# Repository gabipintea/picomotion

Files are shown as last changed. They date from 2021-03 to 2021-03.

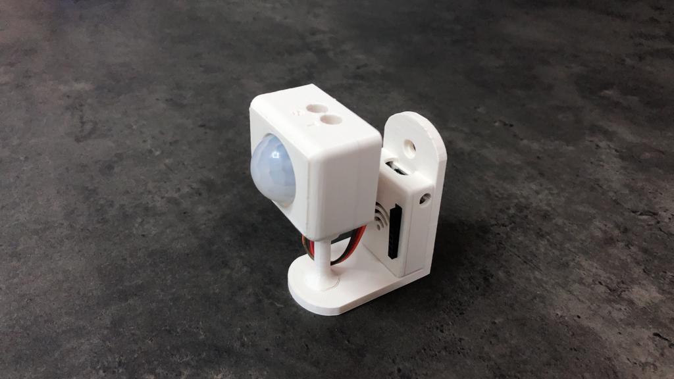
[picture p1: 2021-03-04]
pics/pic1.jpeg

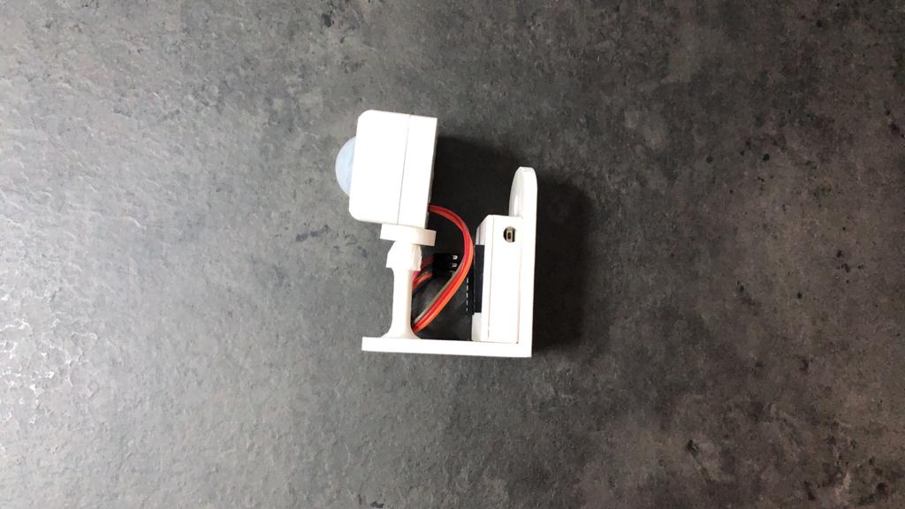
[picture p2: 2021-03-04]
pics/pic4.jpeg

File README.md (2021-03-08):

# PicoMotion - simple motion sensor for Home Assistant
PicoMotion is an open-source, simple, ready-to-mount, and ready-to-use motion sensor designed to be easily mounted on a wall, even upside down, to be easily adjusted for the use case and to flawlessly work within Home Assistant, by the means of ESPHome.

## Hardware
The hardware is comprised of:
- WeMos D1 Mini ESP8255 Development Board
- HC-SR501 PIR Sensor
- 3 Jumper wires + optional D1 mini headers
- 3D printed enclosure (STLs provided)
- 5V/1Amp DC Power supply
- micro-USB cable
- appropriate mounting screw

## Software
The firmware is written with ESPHome tool, flashed either via ESPHome-flasher, or from ESPHome Add-on within Home Assistant the first time. Afterward it can be OTA flashed. (both .yaml and compiled .bin provided)

## Open-source
As the sensor is made using open-source hardware and software, the whole kit is also open-source, so feel free to come up with feedback, use it, improve it and share it.

Thanks to Home Assistant and ESPHome! The core of the sensor is based on these two amazing pieces of software.

#### Adding to the below instructions, I highly recommend reading the Quick Start guide, provided in this repo.

## Instructions
1. After you got all the needed parts, you need to flash the firmware on the D1 mini.

Method 1: Download and use the .bin file in this repo, connect your D1 mini/ESP-based MCU to your PC using a micro-USB cable and flash the file on the board using ESPHome-flasher utility, for your OS. (https://github.com/esphome/esphome-flasher/releases)

Method 2: If you already have ESPHome Add-on installed, then create a new node, use and modify accordingly the .yaml file provided in this repo and flash your D1 mini directly from the system running ESPHome.

2. Disconnect power and connect the PIR Sensor to GND, 5V and Signal pin (default: D4 on D1 mini, for visual blue led feedback on motion detection).

3. Use the recommended 5V/1Amp DC power supply for powering the D1.

4. If you have added a new node in ESPHome Add-on and changed the WiFI SSID already, then your device should appear online after a few seconds and be recognized by auto-discovery feature of your Home Assistant.
If you did flashed the .bin file in this repo, then wait a few minutes, as the D1 will fail to connect to the SSID a few times and will eventually enable a hotspot AP, named Picomotion X (where X should be a unique number across your PicoMotion devices on the local network). Connect to the hotspot, dismiss the alerts of having "No Internet", navigate to http://192.168.4.1 using a browser, select your preffered WiFi network, type the password and hit "Save". The D1 will reboot and connect to your WiFi network.

5. After Home Assistant dicovery notfies you (if not, you can trigger that by manually restarting the Server), you can configure the new ESPHome node using the Integrations wizard and providing the api password, which is set in the .yaml file. You will get by default a motion class binary sensor, which gets triggered by warm bodies, like humans/animals. 
#### Note: If using the provided .bin file, the random api password for the provided sample is: HDLlLT2YEIci

6. Enjoy using the motion sensor in your light automations, presence detection ideas, alarm system or whatever. You can adjust the sensitivity and delay after trigger, using the two knobs, on top of the sensor.

## 3D enclosure instructions
1. Slice the STLs in your preffered slicer. The settings in CURA 4.8.0, for a Creality Ender-5, used for printing the sample in the pictures are:
- 0.2 layer height
- 20% infill
- 1.2 wall thickness
- 200C print temperature (differs for each material; for the sample Premium PLA/PHA was used)
- 40mm/s print speed
- Touching Buildplate support (for the sensor bottom especially)

2. Insert the D1 mini in the case, letting the headers facing upwards and use a small amount of superglue, to fix it on the back of the support.

3. Mount the support on the wall, using the appropiate screw for your material.

4. Push the PIR sensor in the case, connect 3 jumper wires to the pins on the back, assemble the back of the sensor.

5. Insert the printed tightening ring onto the shaft of the sensor, insert the sensor on the spherical mount, adjust it's position and secure it by pulling down the ring.

6. Connect the jumper wires to the D1 on the left-side header, from top to bottom (5V, GND, D4).

Credits:
- Home Assistant (https://www.home-assistant.io/)
- ESPHome (https://esphome.io/)
- Thingiverse (https://www.thingiverse.com/)
    
    especially:

        - BrainFever (https://www.thingiverse.com/brainfever/designs)
        
        - Electronlibre (https://www.thingiverse.com/electronlibre/designs)
        
        - Hills8 (https://www.thingiverse.com/hills8/designs)

## Picromatics

If you need something already made, the kit, the plug-n-play device, the 3D printed case or you just want to know more about me and my IoT company, write me an email or find me on LinkedIn/Facebook.

#### https://picromatics.com
#### contact@picromatics.com
#### gabriel.eugen.pintea@gmail.com

Turn your “dumb” home into a Smart Home! Picromatics develops professional IoT Solutions and offers Smart Integration Services for all your needs, being your beloved home or your business. 

IT & IoT Consulting services, Smart Home integration, custom hardware development, custom software development, product design, 3D printing and more...

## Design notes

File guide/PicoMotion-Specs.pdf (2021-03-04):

Datasheet and Specifications

- WeMos D1 Mini ESP8255 Development Board

Overview
This mini development board is based on the ESP-8266EX chip and is useful for applications that need wireless data transmission (2.4GHz). It is compatible with Arduino IDE and NodeMCU firmware. It features 11 digital input/output pins, all pins support interrupt/PWM/I2C/one-wire (except D0), and 1 analog input with 3.3V
maximum input. With this product, you can build innovative projects like you can control lights or appliances in the house.

Specifications
Chip: ESP-8266EX
Compatible with Arduino IDE Compatible NodeMCU firmware GPIO pins: 11
1 pin ADC (0 V to 3.3 V)
Max Input Voltage: 24 V
Operating Frequency: 80 / 160 MHz Flash Memory: 4MB
I2C interface
Size: 34.2 x 25.6 mm
- HC-SR501 PIR Sensor

Overview
The HC-SR501 sensor is based on pyroelectric infrared technology, it features high sensitivity, high reliability, and low-voltage operation. It is widely used in alarms and auto-sensing electrical equipment, especially in battery-operated products.

Specifications:
Operating Voltage Range: 5 V to 20 V
Power Consumption: 65 mA
TTL Output: 3.3 V, 0 V
Lock Time: 0.2 sec
Sensing Range: <120°, within 7 meters Temperature Range: -15° C to +70°
- 3D printed enclosure

The enclosure is made out of premium PLA/PHA material, non-toxic, with no odor. It is created using FDM 3D printing technology.
Note: Take note of the fact, that 3D printing can offer great quality, but as the printing technology is not yet flawless, there may be some minor artifacts, that does not affect the functionality of the case. (e.g. layer lines, plastic blobs, stringing lines, etc.)

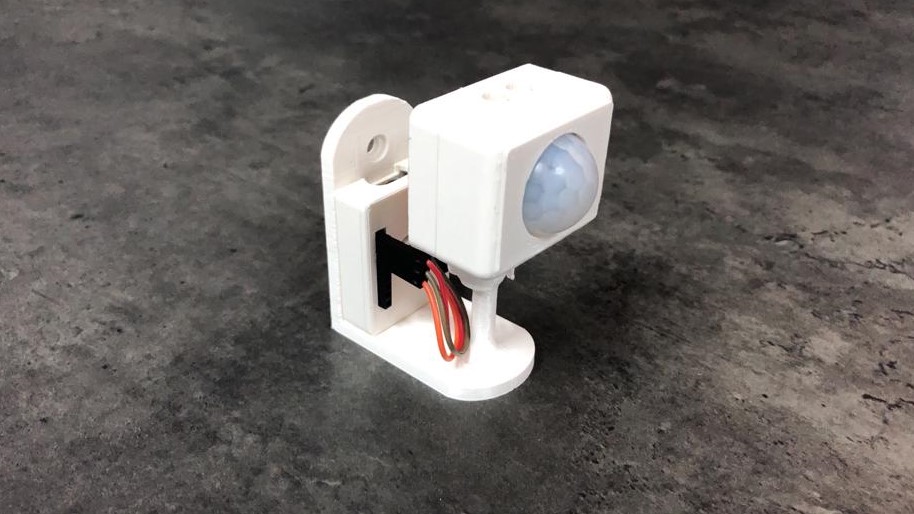
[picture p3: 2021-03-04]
pics/pic2.jpeg

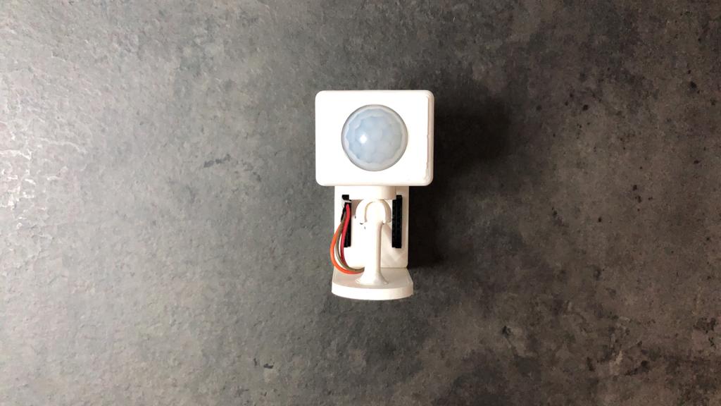
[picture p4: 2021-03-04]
pics/pic3.jpeg

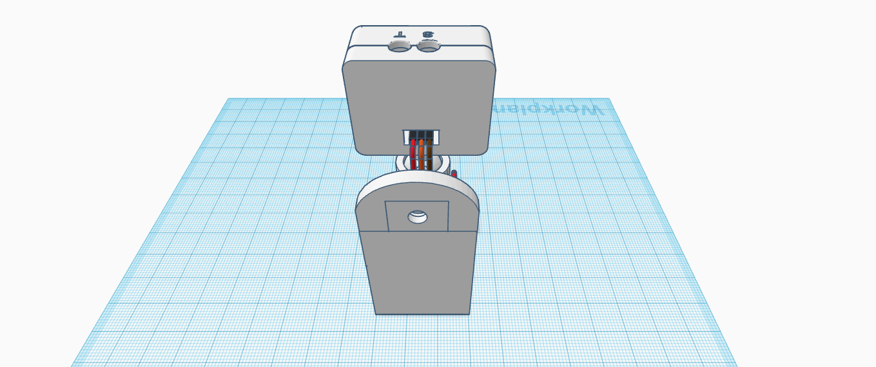
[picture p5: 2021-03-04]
3D/PicoMotion-2021-01 (3).png

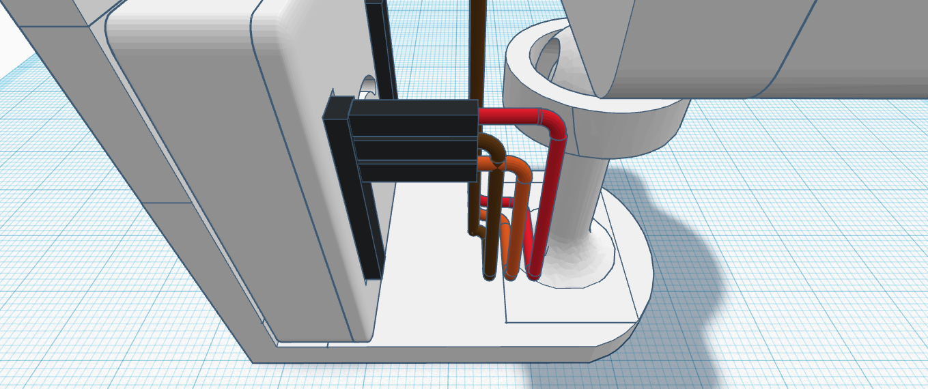
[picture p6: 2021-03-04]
3D/PicoMotion-2021-01 (4).png

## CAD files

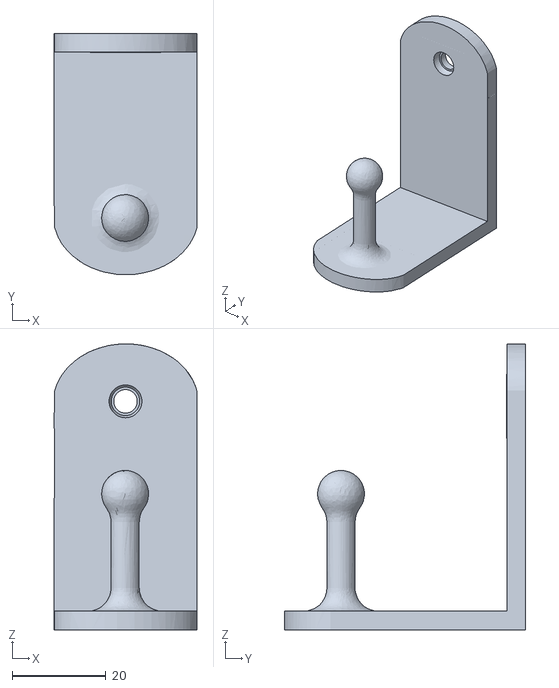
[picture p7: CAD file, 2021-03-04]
3D/stl/PicoMotion-2021-01-Wall_Support.stl
30.4 x 51.4 x 60.9

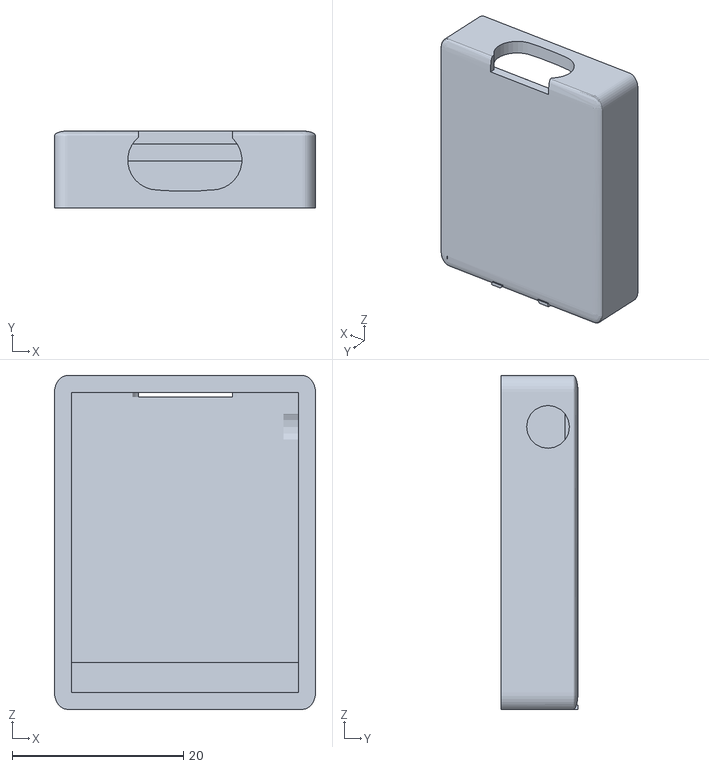
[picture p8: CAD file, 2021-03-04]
3D/stl/PicoMotion-2021-01-D1-Base.stl
30.5 x 9.00 x 39.0

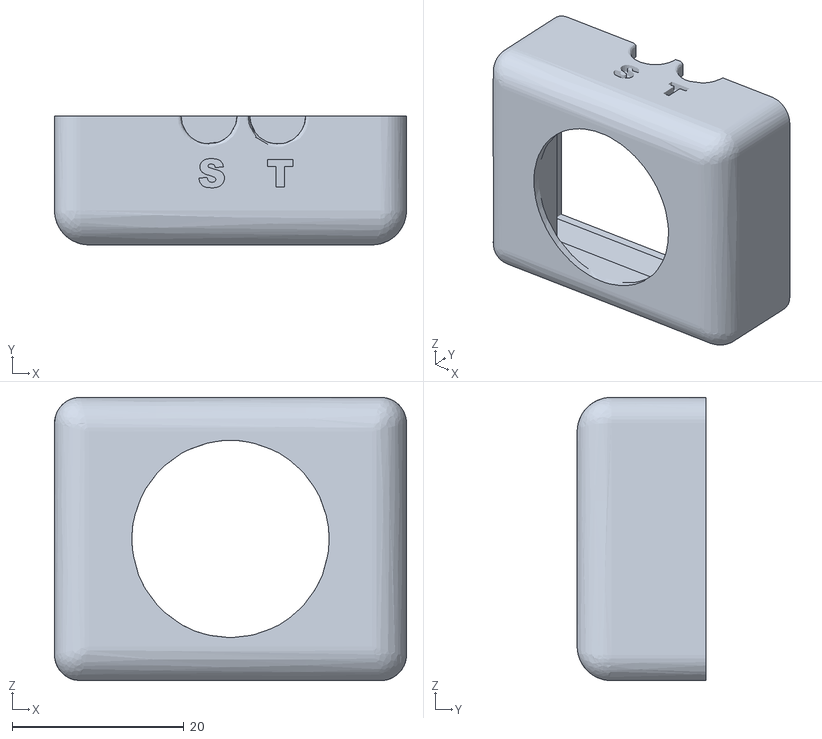
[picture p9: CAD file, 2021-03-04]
3D/stl/PicoMotion-2021-01-Sensor_Top.stl
41.0 x 15.0 x 33.0

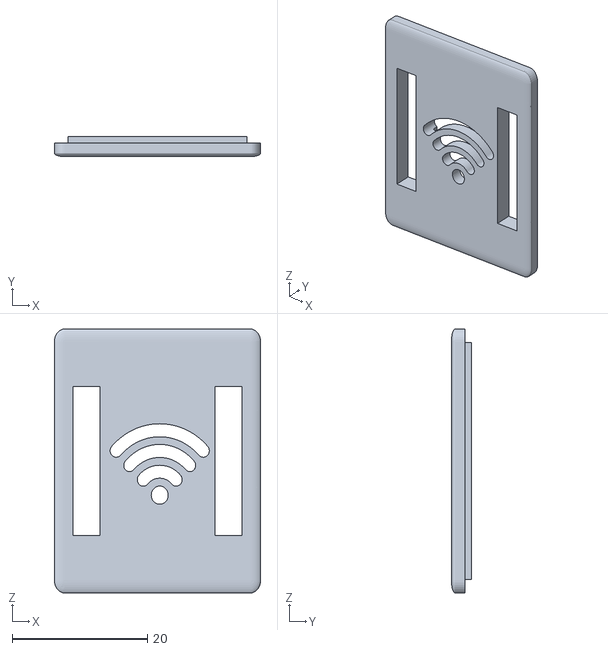
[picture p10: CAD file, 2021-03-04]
3D/stl/PicoMotion-2021-01-D1-Lid.stl
30.5 x 3.00 x 39.0

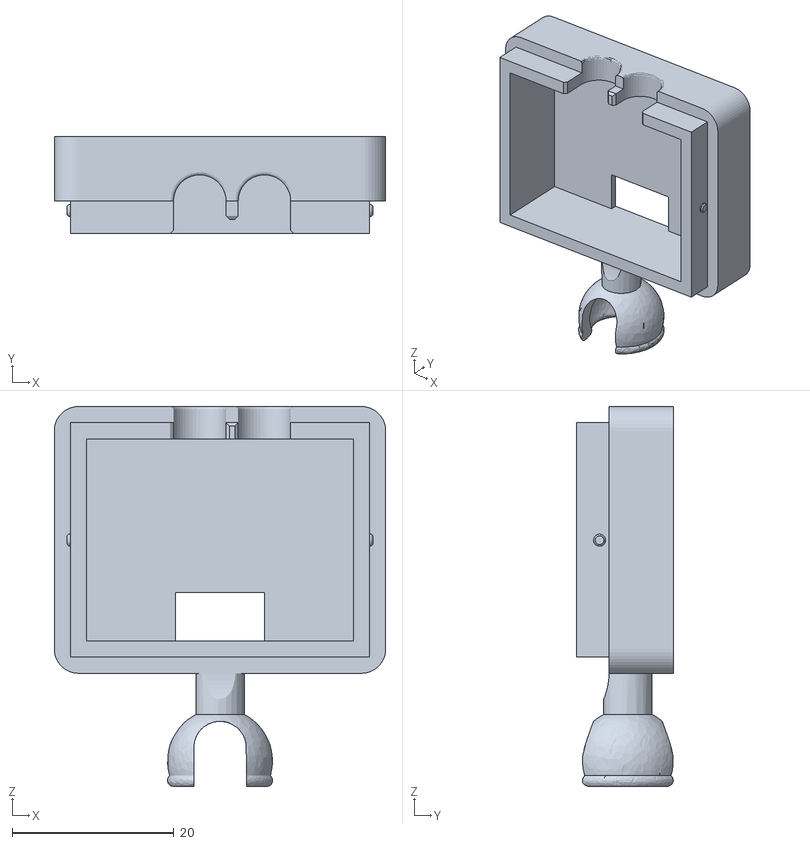
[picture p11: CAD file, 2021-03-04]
3D/stl/PicoMotion-2021-01-Sensor_Base.stl
41.0 x 12.0 x 47.0

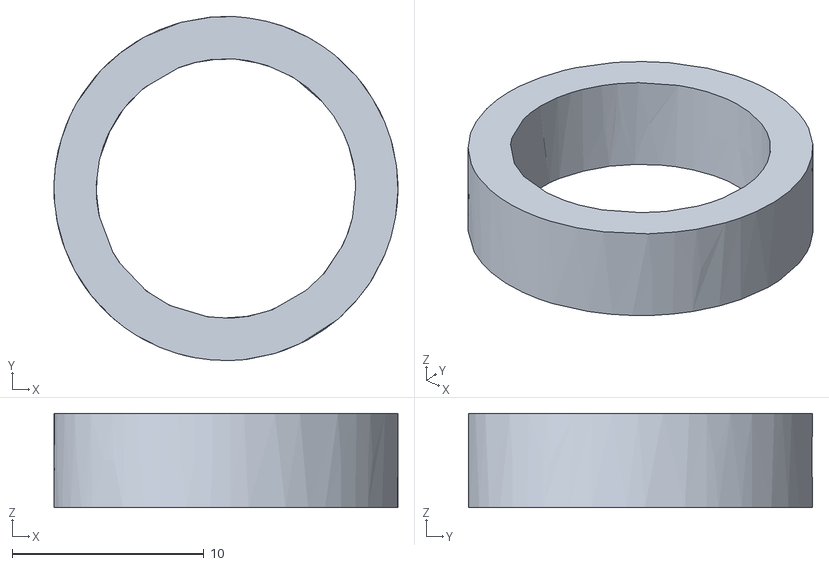
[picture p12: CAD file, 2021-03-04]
3D/stl/PicoMotion-2021-01-Ring.stl
18.0 x 18.0 x 4.91

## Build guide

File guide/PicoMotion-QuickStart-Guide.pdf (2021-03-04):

PicoMotion
v.2021.01

Quick Start Guide

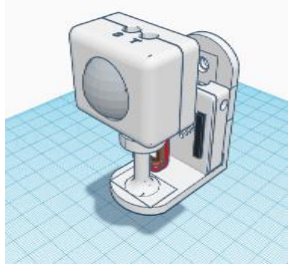
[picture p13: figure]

2021

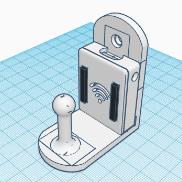
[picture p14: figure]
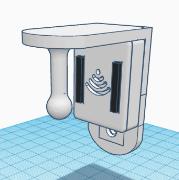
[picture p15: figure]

Powered by Home Assistant™ and ESPHome

### 1. Introduction

Thank you for choosing PicoMotion for your smart motion detection needs and presence-based automation. PicoMotion is an open-source design. Out of the box, it is running ESPHome-generated firmware, intended to be used with a Home Assistant™ server, providing local control and privacy by design.

### 2. Inside the box

The PicoMotion kit consists of:
- D1 mini WiFi module (2.4GHz) with ESPHome-based firmware
- HC-SR501 PIR motion sensor
- Jumper wires
- micro-USB Type-B cable
- 5V DC power adapter
- Custom 3D printed enclosure
- (optional) mounting screw

If any of the components is missing, please contact Picromatics support on: contact@picromatics.com

### 3. Getting started

Step 1: Remove all the packaging materials.
Step 2: Using the provided mounting screws, or any other more appropriate screws for your mounting place material, secure the support according to your needs. The sensor can be mounted vertically, either with the USB connector upward or downward, depending on your custom case.
Step 3: Insert the jumper wires, exactly in the below order.
Sensor, as you look from behind (left-to-right): red, orange, brown

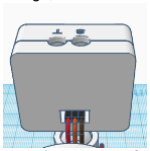
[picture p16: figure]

From left to right: R, O, B

WiFI module on the left black header, as you look from the front side (top-to-bottom): red, brown, orange

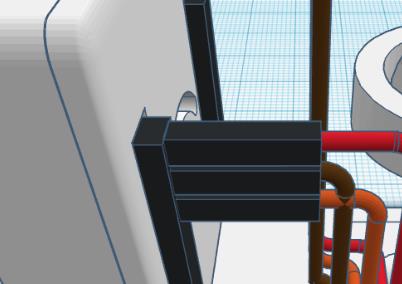
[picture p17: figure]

From top to bottom: R, B, O

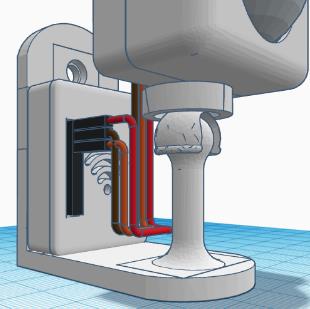
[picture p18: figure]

Step 4: Put the tightening ring on the shaft

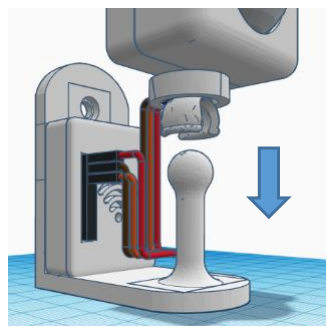
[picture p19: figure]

of the case and, gently push the case on the spherical stem, until it fits properly.

Step 5: Adjust the position of the sensor, according to your needs. The PIR sensor should sense Infrared radiation emitted by living bodies, within 120° angle and 7 meters. Secure the position by, gently, pushing down the tightening ring on the spherical stem.

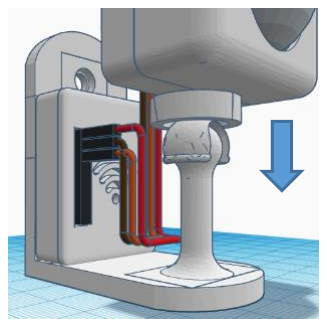
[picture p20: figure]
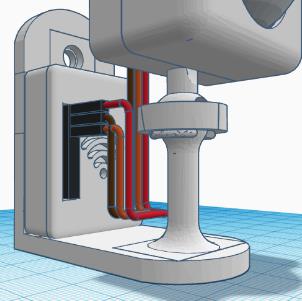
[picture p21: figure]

Step 6: Connect the power adapter to an adequate supply (like a wall socket) and connect the USB cable to the sensor.

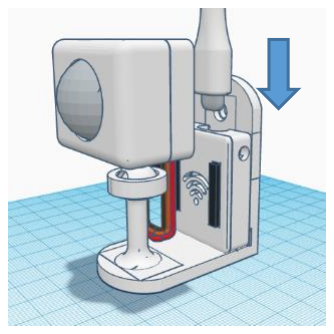
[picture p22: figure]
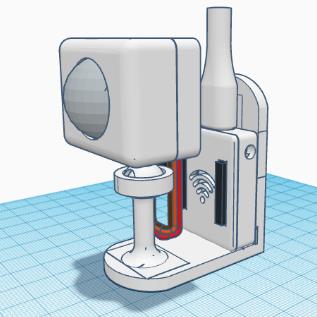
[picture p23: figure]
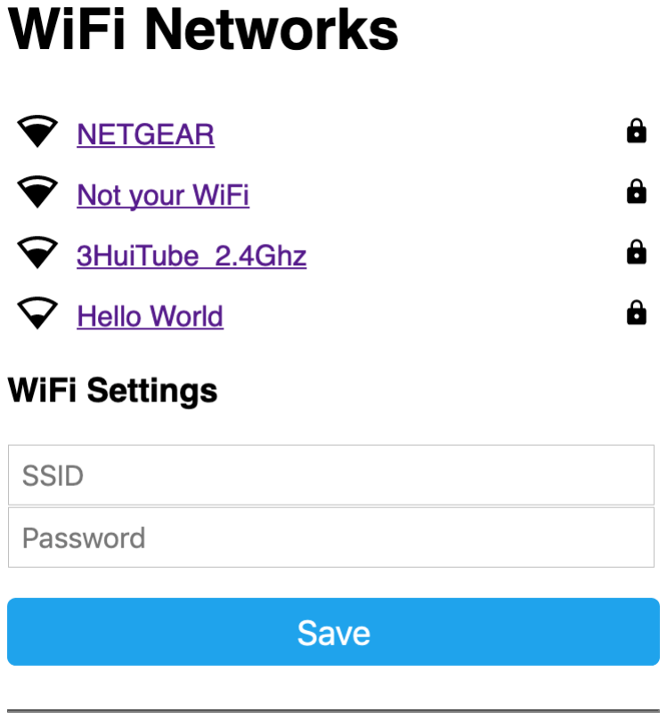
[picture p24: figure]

Step 7: After powering on, the sensor will try to connect to the last known WiFi network. After 1 minute of failed attempts, the module will start a WiFi hotspot with the SSID: Picomotion X (where X is the ID no.) Connect to the hotspot using a wifi-enabled device using the provided password stuck on the bottom of your PicoMotion.
Step 8: If your device alerts you, that the WiFi network does not have an active or reliable Internet connection, just continue and select “Keep WiFi connection”. If it prompts you to sign in or automatically navigates to your browser, just continue.
Step 9: If your device does not automatically navigate to the setup page, or does not prompts you to sign in, manually open up your browser and navigate to http://192.168.4.1/
Step 10: The configuration page opens up and displays a list of available, discovered WiFi networks. Select the network you wish, the sensor will reside in, enter the wifi password of your network, and hit “Save”. After a few minutes, the sensor will restart and connect automatically to your WiFi network.
Note: The sensor should be on the same local network as your Home Assistant™ server.
Step 11: Let Home Assistant™ automatically discover the sensor. If the notification to configure a new ESPHome device does not appear in a few minutes, you can manually trigger the discovery with a restart of the server. (make sure the discovery component is enabled, check online resources for documentation)

Final step: On the Integrations page from Home Assistant™ you should hit the “Configure” button on the newly discovered ESPHome device. Click “Submit” and enter the password, stuck on the bottom of the support.

Troubleshooting
1. “I get a strange behavior”
Try adjusting the sensitivity and the timer between triggers from the knobs on top of the sensor, labeled “S”, and “T” respectively. Restart the device, by pushing the small restart button on the right side.
2. “The device becomes often unavailable” Make sure the sensor has a reliable WiFi connection and power supply. Try setting up a static IP address from your router settings. Restart the device, by pushing the small restart button on the right side. Try restarting your Home Assistant™ server.

If everything fails, try to find assistance on Home Assistant™, ESPHome and Picromatics websites, forums, repositories or write an e-mail to
contact@picromatics.com
